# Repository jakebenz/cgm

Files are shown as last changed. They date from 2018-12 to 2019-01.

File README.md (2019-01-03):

# cgm
Documenting my journey of reverse-engineering the Dexcom G5 Continuous Glucose Monitor (CGM).

This repository serves to host all of the information that I gather surrounding the Dexcom G5 CGM.

There are many topics covered, each of which has its own folder. I recommend reading the background page first, and working your way from there.

**If you are only interested in learning how I replaced my Dexcom G5 batteries, head to the battery-replacement folder.**

-
#**The information contained herein does not constitute medical advice, nor should you rely on any of the information or methods that I present as being medically equivalent to currently available Health Canada or FDA-approved means of managing blood glucose or diabetes.**
-
#**This git is dedicated to experimenting with currently available open source DIY, as well as commercially available means of measuring and managing blood glucose, and should NOT be used as a basis for dosing insulin or making medical decisions. If you have medical concerns, contact your physician or your local emergency services.**

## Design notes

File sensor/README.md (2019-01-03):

**Understanding the Dexcom G4/G5 sensor**
-

All components

The Dexcom G4/G5 Sensor (hereafter "Sensor") is a medical device that comprises several components necessary for its utility.

Adhesive fleece et al.
Adhesive fleece et al.
1. **Adhesive fleece**, used to adhere to the skin. Shown here still attached to the rest of the components.

Sensing filament
2. **Sensing filament**, inserted subcutaneously to approximate blood glucose through measuring conductivity of interstitial fluid. Partially covered by a piece of shielding plastic—perhaps teflon.

Transmitter mount
3. **Transmitter mount**, a molded piece of polycarbonate which houses the other components, as well as provides a means of mounting the Transmitter securely.

Waterproof substrate
4. **Waterproof substrate**, a molded piece of silicone rubber designed to waterproof the electrical connection between the Sensing filament and the Transmitter.

Conductive rubber
5. **Conductive rubber**, two cylindrical pieces of conductive rubber material through which the Sensing filament passes, in order to electrically transmit the signal.

In order to approximate a blood glucose, the Sensor must measure some analog signal from its inserted Sensing filament and transmit this signal to the Transmitter, to be transduced into a digital signal and sent to the Receiver.

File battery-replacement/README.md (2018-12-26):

**To guide your battery replacement, I have created an annotated album of high-quality images found in the *[guide](https://github.com/jakebenz/cgm/tree/master/battery-replacement/guide)* folder.**

**STL Print Instructions:**

At least 80% infill

Material order of preference: ABS/Nylon>PETG>PLA

Print without supports with clips facing upward

Adapted from BillyBean's [Dexcom G4 Cover](https://www.thingiverse.com/thing:2716515)

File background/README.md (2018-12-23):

**A background on the Dexcom G5 Continuous Glucose Monitoring (CGM) System**

**Part 1: Diabetes, insulin, and blood glucose**

The Dexcom G5 Continuous Glucose Monitoring System is a suite of software and hardware products sold by Dexcom, Inc. designed to facilitate measurement of blood glucose in individuals with type one diabetes mellitus (T1D). T1D is an autoimmune disease wherein some insult (genetic, environmental, infectious, etc.) causes the body to recognize one's own insulin-secreting beta cells of the pancreas as foreign, leading to an immune response to destroy said beta cells. This process occurs over the course of months, and eventually the immune response will destroy the body's beta cells to the point where insufficient insulin is being produced to accomodate the needs of the individual. There are currently no commercially-available means of restoring the lost beta cells, and thus people with T1D must take in exogenous insulin, often by needle or subcutaneous infusion via insulin pump. When one consumes food, the food is digested and glucose eventually ends up in the bloodstream, to be conducted to other organ systems by insulin. Insulin is a hormone which binds different receptors around the body to facilitate the movement of glucose from the blood into various tissues, like the brain, muscles, liver, and other organ systems. Dosing requirements are unique to each individual, and are affected by many variables, such as body composition, activity level, age, biological sex, stress, illness, and foods consumed, as well as many other variables. There are many deleterious effects of having elevated blood glucose, specifically when blood glucose is chronically elevated. These effects can be broadly categorized into small vessel disease, large vessel disease, and neurological disease. Optimizing blood glucose control such that blood glucose is maintained at around 5.5mmol/L (100mg/dL) is known to correlate with decreased long-term side effects of diabetes (both type 1 and type 2.) It follows, then, that having a continuous measurement of blood glucose may allow for greater control of blood glucose, and therefore less long-term complications relating to diabetes. This is the impetus behind development of continuous glucose monitoring systems such as the Dexcom G5 CGM system.

**Part 2: Financial impact of Dexcom G5 CGM**

Dexcom's CGM system is expensive and often not covered even under the best private drug benefits in Canada. A year of transmitter and sensor costs $3,108CAD, and is sold under contract by Dexcom. This equates to $259CAD/month, which is just under $10/day. Transmitters are said to last 90 days, after which time a notification appears on your receiver device stating that the battery is low and to order a new transmitter. Then, at 112 days, the device will shut down and not reconnect, stating that the battery has died and that the device no longer will function. The problem is that the device still has sufficient battery left, and this can be shown by pairing the transmitter with a third-party app such as XDrip-iOS (formerly Spike-iOS) on iPhone, or XDrip on Android. My transmitter went until 195 days before the battery truly died. To be fair to Dexcom, it is likely that they were only able to prove that the device would last a minimum of 112 days because of variability in the supply chain of battery supplier and chip suppliers, likely having slight variations in battery capacity and power consumption. 

There is a destructive means of replacing batteries in the transmitter, which I will document elsewhere in this git. There are many good reasons for developing the transmitter in such a way that is disposable: its waterproof rating because it is sealed, robustness, lack of surfaces for harmful organisms to grow, smooth surface to prevent catching on clothing, as well as others, I am sure. But, it is my opinion that a strong driving factor in the decision to make this a disposable product is profitability. The 112-day battery limit even with reliable charge in the batteries corroborates this theory. If your customers require a replacement every 90/112 days, then you have a constant stream of revenue to further appease shareholders (and, admittably, fund future research and development.) I will leave the rest of the politics surrounding this issue to another discussion forum, and will continue with my documentation of the Dexcom G5.

**Part 3: Reverse engineering**

From Dexcom's patent filings ([US7591801B2](https://patents.google.com/patent/US7591801B2/en?q=continuous&q=glucose&q=monitor&assignee=Dexcom%2c+Inc.), [US20120108934A1](https://patents.google.com/patent/US20120108934A1/en?q=continuous&q=glucose&q=monitor&assignee=Dexcom%2c+Inc.)) we can see the overall device comprises a "sensor", which is made up of a subcutaneously-inserted metal filament connected to a mounting structure with a means of electrically connecting to a "transmitter", a device designed to interpret the analog signal coming from the sensor. This transmitter is designed to be robust and waterproof (it holds an IP28 rating, meaning it is not extremely shock-resistant [the first digit refers to physical robustness, ranging from 0 to 6], but holds the highest IP rating for waterproof [the second digit ranges from 0 to 8])

From Dexcom's filings, they refer to the sensor as a *continuous analyte sensor*, and the transmitter as a *sensor electronics module*. Dexcom rightfully obfuscates their hardware in order to protect their patent, so I must assume the contents of their transmitter device at the moment. Once I receive an extra transmitter, I intend on sacrificing it in order to reverse-engineer the device with ample documentation to be shared. This will come in the form of an update to this README.md.

**The transmitter likely contains the following technology, based on preliminary findings and research:**
1. Two SR1120W (silver oxide) batteries wired in parallel (1.5V nominal)
2. A Low-Energy (LE) Bluetooth transmitter IC with antenna (note they may be using a custom SoC, perhaps based on Nordic Semiconductor's [N52832/nRF52832](https://www.nordicsemi.com/Products/Low-power-short-range-wireless/nRF52832))
3. An IC responsible for transcoding analog data from sensor into digital data to be transmitted by Bluetooth IC (this may not be required if this is integrated into the SoC from 2.)
4. A buck converter IC to power the Bluetooth transmitter IC, as it will not run on 1.5V.

The data transmitted from the sensor+transmitter combo, worn on the arm, is sent to a receiver. An iOS or Android device running software designed to interpret such data over Bluetooth is an eligible receiver, as is Dexcom's own product, which is a small device with a screen to show a UI as well as buttons for user interaction. A teardown of the Dexcom G5 Receiver device by Adrian Black is found [here](https://www.youtube.com/watch?v=mmQgIdNVt7U). The device runs a custom version of Windows CE.

**Step 2: Destructive replacement of batteries in the Dexcom G5 Transmitter**

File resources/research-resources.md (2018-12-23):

[Potential SoC used in Dexcom G5 transmitter](https://www.nordicsemi.com/Products/Low-power-short-range-wireless/nRF52832)

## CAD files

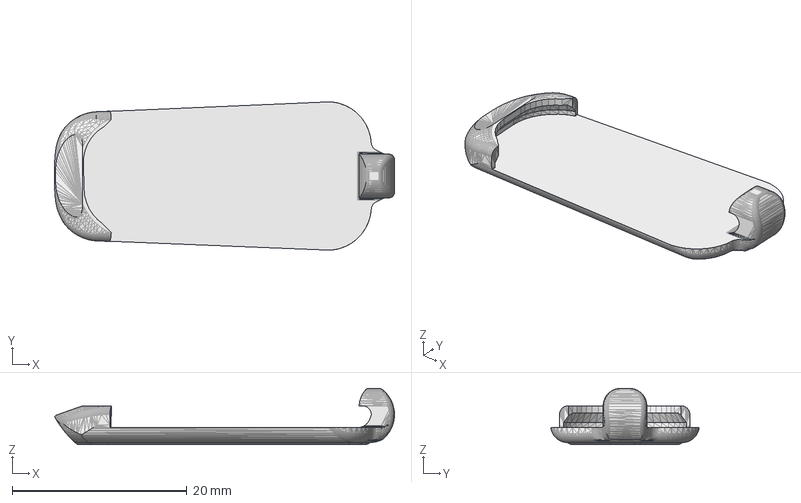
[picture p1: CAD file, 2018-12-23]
battery-replacement/G5_cover_nocutout.FCStd
38.9 x 17.0 x 6.45 mm

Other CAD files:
battery-replacement/G5_cover_nocutout.stl

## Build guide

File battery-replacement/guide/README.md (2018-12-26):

**What you'll need**:
-

1. A **tool to remove material from the top of the transmitter**. The cheapest way to do this is to buy a bench grinder ($40 at Harbor Freight) with an abrasive wheel.

Abrasive wheel on bench grinder from Harbor Freight

2. **Replacement batteries**. Renata 389 is a direct replacement, but you may use SR44 (silver oxide) or LR44 (alkaline). The STL that I provide is designed to function with a Renata 389 or identically-sized 1.5V button cell battery. **You will need two batteries per transmitter**.

Replacement batteries from the Dollar Store

3. Some sort of **epoxy or silicone sealant** to prevent water ingress following battery replacement

Five-minute epoxy from the Dollar Store

4. A **small pointed tool** to stab the spent batteries.
5. A **razor blade** or utility knife to remove small amounts of material.
6. A **3D-printed cover**, such as the one I have on this git ([HERE](https://github.com/jakebenz/cgm/blob/master/battery-replacement/G5_cover_nocutout.stl)).

3D-printed cover

_Optional_:

- A spot welder to create a more robust electrical connection.
- A brass wire brush to clean the battery contacts and terminals.

**Step 1: Remove surface material**
-

Grinding transmitter

Carefully begin to remove material from the top of the transmitter, being sure to grind it relatively flat.

Surface after grinding

The surface after a bit of grinding.

Surface revealing batteries and tabs
Surface revealing batteries and tabs
Surface revealing batteries and tabs

You should stop grinding at this point and move to the razor or sharp pointed tool to remove the rest of the resin on top of the batteries and terminals.

Removing material with sharp tool

**Step 2: Replace batteries**
-

Battery tab revealed

Removing spot welds with utility knife. Cut toward your chum, not your thumb.

Battery tab revealed

Here, one battery tab has been removed from the surface of the battery. Be careful with the tabs as they break easily.

Both battery tabs revealed

Both battery tabs revealed.

Destructive removal of batteries

I'm sure there's a better (read: safer) way of doing this, but I find that piercing the battery and prying it out is easiest. Be careful, wash your hands if you get any battery electrolyte on yourself.

Pry the battery out

Pry the battery out, and then repeat the same process for the other battery.

Both batteries removed

Both batteries removed. Time to put the new ones in.

Push in the new batteries in the same orientation as the originals

Push in the new batteries in the same orientation as the originals. Positive terminal facing outward.

Test the voltage

Test the battery voltage across the two terminals. It should read at least 1.55V.

**Step 3: Seal the transmitter with epoxy and 3D-printed cover**
-

Get your epoxy ready
Mix the epoxy well

Get your epoxy ready and mix it.

***Optional step***: Spot weld battery tabs onto positive terminal of batteries. 800A/2V/40ms works well. I've found that a bent battery terminal to make contact is good enough, but likely is higher resistance than a spot welded connection. I have not noticed a difference in battery life or transmitter temperature between the two methods.

Cover the batteries and terminals to prevent water ingress

Cover the batteries and terminals to prevent water ingress.

Snap the 3D-printed cover on
It snapped
All epoxied up

Snap the 3D-printed cover on. If the material stresses too much, it may crack. Just cover the crack in epoxy if this happens.

**Step 4: Reset transmitter clock or pair with XDrip/Spike/Loop**
-

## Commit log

2018-12-23 3D files, print instructions added
    [G5_cover_nocutout.FCStd, G5_cover_nocutout.stl]
2018-12-24 Added tutorial for battery replacement
2019-01-03 added sensor documentation
